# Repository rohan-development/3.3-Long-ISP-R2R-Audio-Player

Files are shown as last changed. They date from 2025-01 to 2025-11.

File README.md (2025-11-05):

The purpose of this ISP, the 8-Bit Audio Player is to play rotary-encoder-selectable-by-name 8-bit, 16 KHz, mono wav files using an R/2R digital to analog converter in place of a traditional I2C or SPI DAC.

The attached code files allow 2 ATmega328Ps to be used in tandem to control a TFT panel, as well as the R2R DAC.

See attached Report.pdf for further details.

Video overview: https://www.youtube.com/watch?v=TbR3IQ8DSpg

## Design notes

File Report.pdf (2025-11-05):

## Project 3.3 Long ISP: 8-Bit R/2R Audio Player

### Purpose

The purpose of this ISP, the 8-Bit Audio Player is to play rotary-encoder-selectable-by-name 8-bit, 16 KHz, mono wav files using an R/2R digital to analog converter (see Project 2.1) in place of a traditional I2C or SPI DAC.

### Reference

Project description: http://darcy.rsgc.on.ca/ACES/TEI4M/2425/ISPs.html#logs
Project proposal: http://darcy.rsgc.on.ca/ACES/TEI4M/2425/images/RJAudio.png Project GitHub: https://github.com/rohan-development/3.3-Long-ISP-R2R-Audio-Player
PCB schematic: https://oshwlab.com/rjamal/ipod-thing

### Theory

There are 2 main classes of audio files: compressed audio, and uncompressed. The dominant audio file format in modern devices is MP3, which is a type of compressed audio. In order to play most standard audio files (regardless of compression), samples of the amplitude at a known sample rate must be obtained. In an uncompressed audio file, the raw sample values are already available in the file; in a compressed audio file, the samples must be obtained by applying an algorithm to the compressed data. These sample rates are then converted to an analog voltage, using a DAC, and amplified to be perceived as sound (see Figure 1).

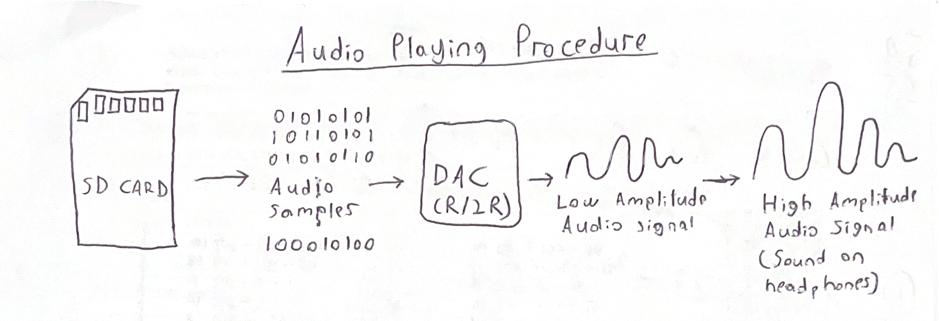
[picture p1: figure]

Figure 1. Audio Playing Sequence Using a DAC

When referencing the Atmega328P, most compression algorithms require significantly more computing power than available to playback in real time. For this reason, the R/2R audio player utilizes Waveform Audio File Format (WAV) files to store audio data, which simply store the raw discrete samples.

The basic concept of 8-Bit R/2R Audio Player comes from Project 2.1, the R/2R DAC. An R/2R ladder, or DAC, is a simple DAC that converts an 8-bit, discrete value, to an analog voltage between 0 and the supply voltage using the principle of voltage division. It included 8 switches that could be turned on or off, for a total of 256 steps between 0 and 5V. By connecting the 8 switch inputs to a microcontroller, a stored 8-bit digital value can be converted to an analog voltage. In this configuration, the R/2R DAC enables the microcontroller to emulate PWM with true analog voltage, instead of a duty cycle-based approximation.

### Procedure

On a very basic level, to play audio, the 8-Bit Audio Player makes use of an R/2R ladder and 8-bit, 16 KHz WAV files (see Theory section). In this configuration, an ATmega328P reads audio samples from an SD card, and sequentially outputs the samples onto the R/2R ladder at a rate of 16 KHz. To advance through the samples reliably at 16 KHz, a timer 1 interrupt is used. The raw signal from the output of the R/2R DAC is filtered through a capacitor, and then amplified through an LM386 audio amplifier, before finally being sent to
headphones through a 3.5 mm audio jack.

The ATmega328P has only 2 KB of memory, while an average WAV file can be in excess of 5000 KB. To get around this limitation, a buffer is used. An 8-bit unsigned array with 256 locations (256 bytes) is created. In this configuration, the first 256 bytes are read from the SD card and placed in the buffer array. Then, a timer1-driven interrupt with a frequency of 16 KHz is initialized Each time the interrupt is triggered, an index is incremented. In the loop() function, the R/2R DAC is constantly updated with the value of the current index of the buffer array. To do this, the PORTD register is directly manipulated. By wiring the LSB of the DAC to pin 0, the second LSB to pin 1, and so on up to the MSB wired to pin 7, a WAV sample value can be directly put on PORTD, which automatically generates the correct analog voltage. When the index reaches the end of the array, it is reloaded. As a result, the buffer needs to be large enough that the MCU does not access the SD card too often to keep up, but also small enough that it can reload the entire buffer reliably between interrupts. Using this process, the original audio signal can be approximated (see Figure 1).

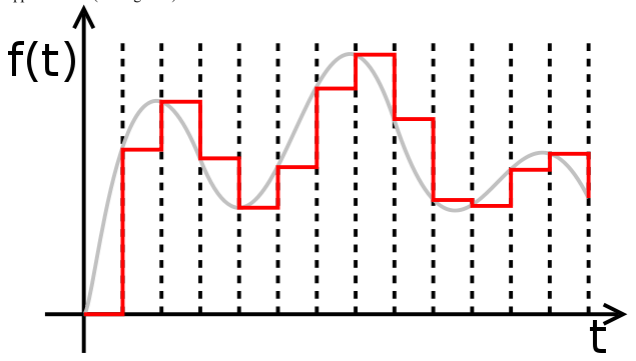
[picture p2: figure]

Figure 1. Audio Signal Approximation using Discrete Signaling

Parts Table
Quantity | Description
13 | Assorted Capacitors
1 | 3.5 mm Audio Jack
25 | ±0.1% 10 KΩ Resistor
38 | Assorted Standard Resistor
2 | Atmega328P SMD MCU
1 | USB-C Connector
1 | LM386 Audio Amplifier
1 | MCP4551T Digipot
2 | 16 MHz Crystal Oscillator

The 8-Bit Audio Player has 2 MCUs used: one “slave” to read from the SD card and update the DAC, and a master to coordinate which song to play, and by responding to user input through a rotary encoder and to control a TFT screen with the song progress and a list of songs. To communicate between MCUs, I2C is utilized. When the master wants to receive any information from the slave, it must send a request. Due to the way that I2C works (see Project 2.6.1), when a request is sent, the same request routine is run. A request routine is a function run when an I2C request is received. This means that the same data point is sent for every request, in a standard configuration. The request routine is simply a function. It is not, strictly speaking, an ISR. This means that many blocks of code can be efficiently run within the request routine, and blocking calls are considered acceptable.

To request multiple data points, a command code
system is implemented. In this configuration, the master sends a code corresponding to a data point, which is placed into a buffer. Then, the master sends a request. Within the request routine, a
subroutine is included for each point (see Figure 2).

The master MCU only has direct access to the display, the rotary encoder, and the I2C bus. Since it does not have access to the SD card, it cannot directly read the song names to put on the display. To read the song names, it requests the data from the player MCU. To do this, it first sends a value of 2, to place in the code buffer (see Figure 2). Then, it requests 32 bytes from the player, which reads the SD card, parses it into a character array buffer, and sends 1 character (byte) at a time to the master which reconstructs the data and parses it into a 2D array of characters. Since the master can only hold a finite number of song names in its 2 KB of memory, the player maintains a global index based on the last song sent. This means that on the next song name request, the next song is automatically sent.

In addition to a request routine, the player MCU has
a receive routine. Unlike the request routine, the
receive routine is an ISR, and it is called when data is written to the player. To aid the command code system, the first byte received is always the code.
Some codes warrant a second byte (see Figure 3).

The code system is global, and not specific to the data direction. As a result, most codes are only valid in either Figure 2 (MISO), or Figure 3 (MOSI). The exception to this is the code 0, which, strictly speaking, corresponds to a song change. When a 0 is received, the songChanged flag is set, and a second byte is read, which is stored into the song number buffer. On the next iteration of the loop, the songChanged flag is picked up, and the song is set to the number in the song number buffer. When the song is changed, the master requires the length of the song each time, which is stored on the slave. As a result, the master sends a data request. Since the code 0 corresponds to a song change, an additional request code is not required; the data point requested immediately after a song change is always song length.

Figure 2. Code Data Correspondences
Code | Data Point
0 | Song length
1 | N/A
2 | Song names
3 | Number of songs

Figure 3. Code Action Correspondences
Code | Action | Extra bytes
0 | Changes song | 1
1 | Toggles Playback | 0
2 | N/A | 0
3 | N/A | 0

To select the desired song, a simple for loop is utilized. In the loop, an index is set such that the loop runs song times. In the loop are two important parts: a next file line, and a hidden file skipping line. In this configuration, since the loop is run a certain number of times, the next file is chosen the same number of times, skipping to the desired file. The index number is built in the same fashion which maps an index value to the filename, so a number can be easily linked with a filename from the display. The hidden file skipping line simply decrements the loop index if the file starts with “._”.

When a song is selected, after the master updates
the slave, it goes to the “now playing” screen
(see Figure 4). This screen shows a music icon, which is stored as an array in program memory, to save RAM. It also shows the current song progress in seconds, the total song length, a progress bar, and the name of the track (see Figure 4).

To display this screen, when the song is selected, the music icon is drawn from program memory (only once, which saves resources). The song track name is also drawn once. Then, a timer1-driven interrupt which triggers once per second is started, updating the song progress in real time. To display the progress bar, the map function is used. It simply maps the song progress from a value between 0 and songLength, to a value between 0 and 100. The progress bar is 100 pixels wide, so a green rectangle with the result of the map is drawn
overtop of the white background bar.

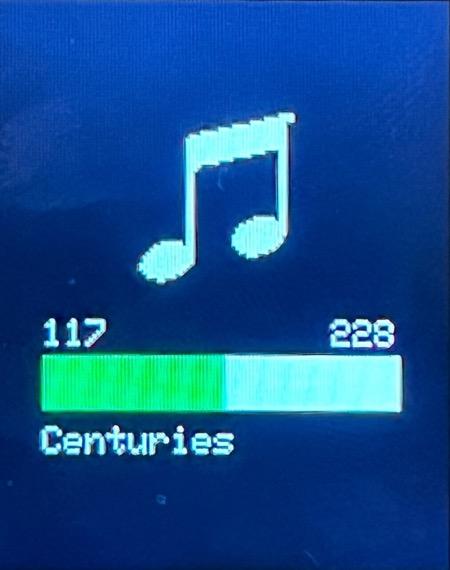
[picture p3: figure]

On the now playing screen, when the rotary encoder is pressed, the master sends a code of 1 to the player, which toggles the OCIE1A bit of the TIMSK register. This bit enables or disables the execution of the ISR on the overflow of timer1. This effectively toggles playback. Since the MCU playing the music is independent from the one connected to the screen, the progress bar is updated independently as well; when playback is started, the master downloads the song length and starts a timer. It does not send a request with the song progress each second.

The PCB for the 8-Bit Audio Player includes a boost converter, as well as a battery charging IC. This allows the 5 V system to be used effectively with a 3.7 V lithium-ion battery, with charging over USB-C. The boost converter steps the voltage up from 3.7 V to 5 V. The battery charging IC regulates the 5 V from the USB-C connector to effectively charge the lithium battery.

Figure 4. Now Playing Screen

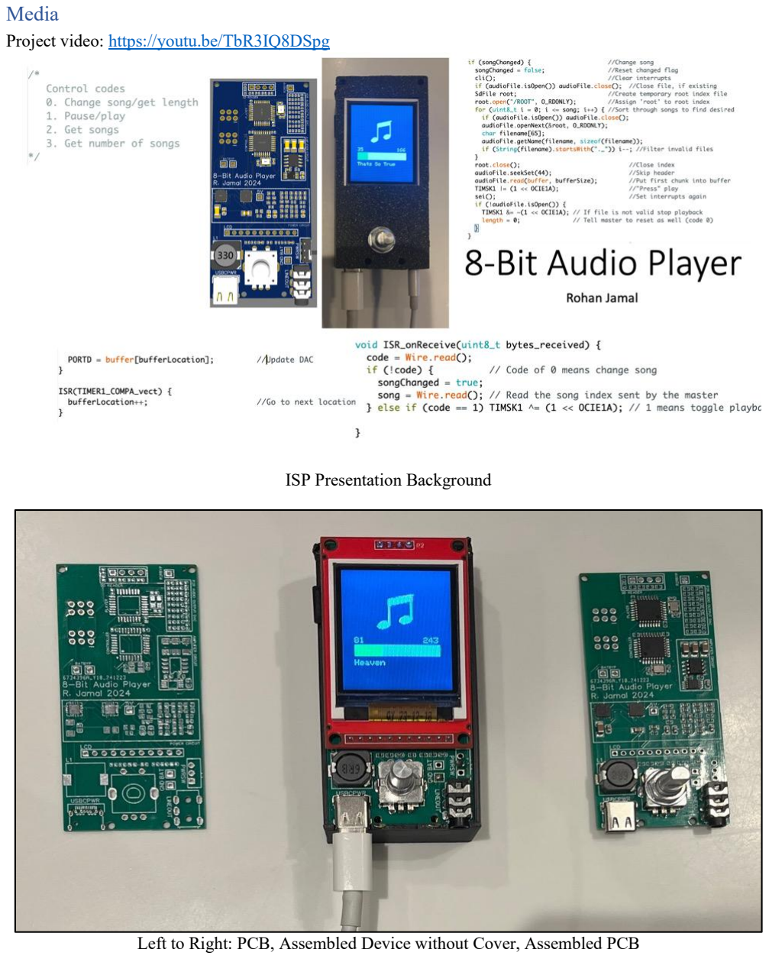
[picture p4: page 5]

### Media

Project video: https://youtu.be/TbR3IQ8DSpg

ISP Presentation Background

Left to Right: PCB, Assembled Device without Cover, Assembled PCB

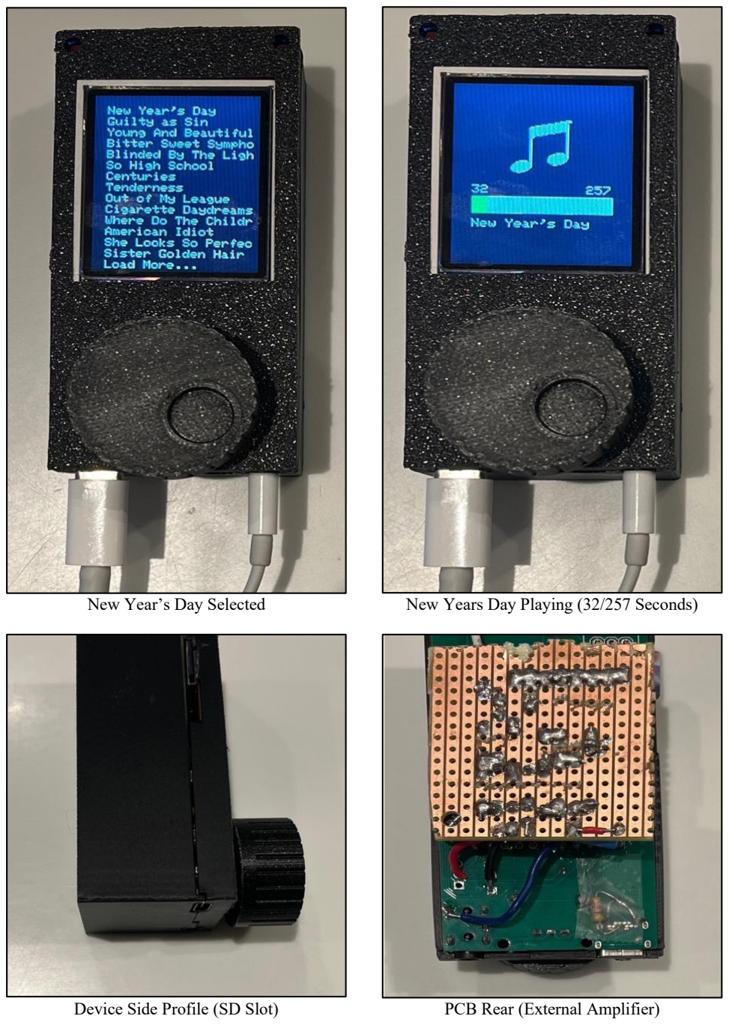
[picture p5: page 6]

New Year’s Day Selected | New Years Day Playing (32/257 Seconds)
Device Side Profile (SD Slot) | PCB Rear (External Amplifier)

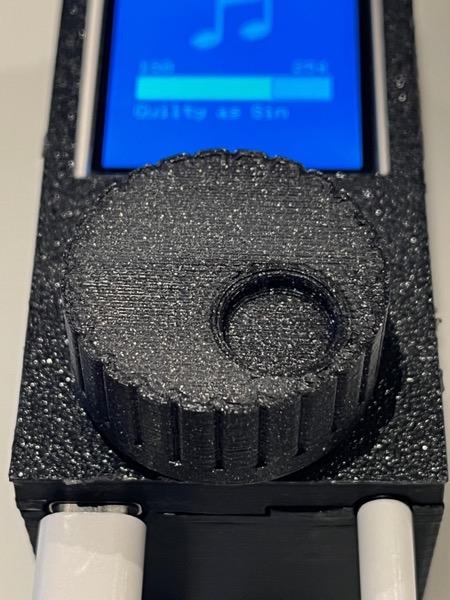
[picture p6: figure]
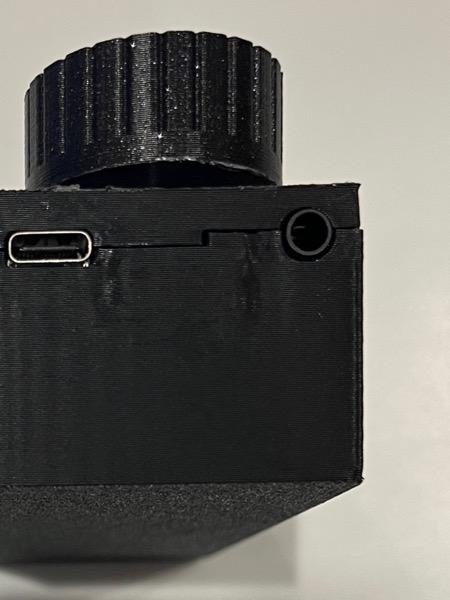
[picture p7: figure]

Rotary Encoder Handle | Device Ports (Bottom)

### Reflection

This has definitely been my favourite ISP thus far. Out of all my ISPs, I think this is my most functional one. My bike speedometer worked in the end, but it was never practical. This audio player is completely practical for sitting in one place whilst doing homework and listening to music. I learned a ton about how music is played in general, I learned a ton of strategies in code (it’s just practice, I suppose), and I really feel that I pushed my PCB design during this project. Overall, I am super happy with the result as I feel that I accomplished just about everything that I said I would (more in some areas). The only “copout” that I ended up going with was 8 bits instead of 12, as all information I found pointed towards inaccuracies of the R/2R ladder beyond 8-10 bits. It also would not have made much sense from a port perspective.

I think that this is really not a testament to any skill but time management. This is something I normally struggle with, but I had my PCB done early enough that I was not scrambling at the last minute, and I had much time to debug and perfect my code and 3D design.

I know that I could have used an ESP32, or some other microcontroller to easily play the audio without an external DAC, but for me, the real satisfaction was building my own DAC from scratch, and working with the limited resources of the 328P

That being said, there are some things that I hope to fix: I think that if I get a chance, I will reorder the PCB, without the power circuit and use larger resistors and capacitors so I can surface mount them myself in order to address a few issues (such as lack of volume control and the absence of a functional onboard amplifier). Overall, this was a great project, and while thinking about my next ISP, I definitely have audio in mind. (My code and EasyEDA files are included in the GitHub and Oshwlab links in Reference).

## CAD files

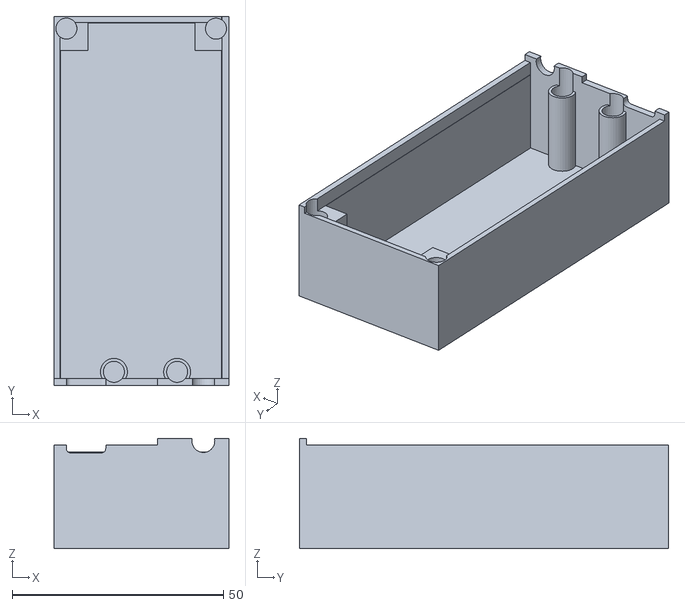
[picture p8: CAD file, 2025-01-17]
Case bottom.stl
41.4 x 87.4 x 26.1

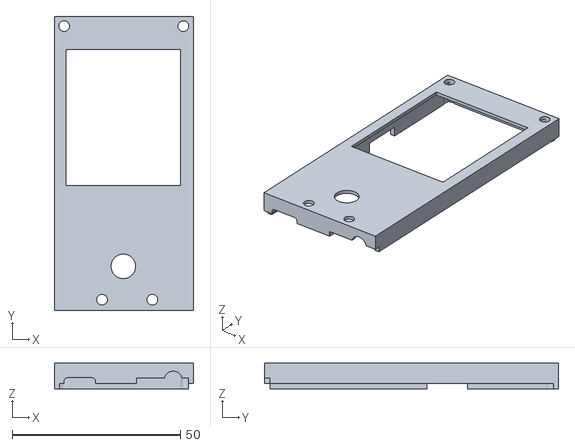
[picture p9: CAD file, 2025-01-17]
Case top.stl
41.4 x 87.4 x 7.69

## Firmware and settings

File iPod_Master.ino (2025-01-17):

const unsigned char note [] PROGMEM = {
  0x00, 0x00, 0x00, 0x00, 0x00, 0x00, 0x00, 0x00, 0x00, 0x00, 0x00, 0x00, 0x00, 0x00, 0x00, 0x00,
  0x00, 0x00, 0x00, 0x78, 0x00, 0x00, 0x00, 0x00, 0x00, 0x07, 0xf8, 0x00, 0x00, 0x00, 0x00, 0x00,
  0x7f, 0xe0, 0x00, 0x00, 0x00, 0x00, 0x0f, 0xff, 0xe0, 0x00, 0x00, 0x00, 0x00, 0xff, 0xff, 0xe0,
  0x00, 0x00, 0x00, 0x1f, 0xff, 0xff, 0xe0, 0x00, 0x00, 0x00, 0xff, 0xff, 0xff, 0xe0, 0x00, 0x00,
  0x01, 0xff, 0xff, 0xff, 0xe0, 0x00, 0x00, 0x01, 0xff, 0xff, 0xff, 0xe0, 0x00, 0x00, 0x01, 0xff,
  0xff, 0xff, 0xe0, 0x00, 0x00, 0x01, 0xff, 0xff, 0xf8, 0x60, 0x00, 0x00, 0x01, 0xff, 0xff, 0x80,
  0x60, 0x00, 0x00, 0x01, 0xff, 0xf0, 0x00, 0x60, 0x00, 0x00, 0x01, 0xff, 0x00, 0x00, 0x60, 0x00,
  0x00, 0x01, 0xe0, 0x00, 0x00, 0x60, 0x00, 0x00, 0x01, 0xc0, 0x00, 0x00, 0x60, 0x00, 0x00, 0x01,
  0x80, 0x00, 0x00, 0x60, 0x00, 0x00, 0x01, 0x80, 0x00, 0x00, 0x60, 0x00, 0x00, 0x01, 0x80, 0x00,
  0x00, 0x60, 0x00, 0x00, 0x01, 0x80, 0x00, 0x00, 0x60, 0x00, 0x00, 0x01, 0x80, 0x00, 0x00, 0x60,
  0x00, 0x00, 0x01, 0x80, 0x00, 0x00, 0x60, 0x00, 0x00, 0x01, 0x80, 0x00, 0x00, 0x60, 0x00, 0x00,
  0x01, 0x80, 0x00, 0x00, 0x60, 0x00, 0x00, 0x01, 0x80, 0x00, 0x00, 0x60, 0x00, 0x00, 0x01, 0x80,
  0x00, 0x00, 0x60, 0x00, 0x00, 0x01, 0x80, 0x00, 0x00, 0x60, 0x00, 0x00, 0x01, 0x80, 0x00, 0x00,
  0x60, 0x00, 0x00, 0x01, 0x80, 0x00, 0x00, 0x60, 0x00, 0x00, 0x01, 0x80, 0x00, 0x3f, 0x60, 0x00,
  0x00, 0x01, 0x80, 0x00, 0xff, 0xe0, 0x00, 0x00, 0x01, 0x80, 0x03, 0xff, 0xe0, 0x00, 0x00, 0x01,
  0x80, 0x07, 0xff, 0xe0, 0x00, 0x00, 0x01, 0x80, 0x07, 0xff, 0xe0, 0x00, 0x00, 0x01, 0x80, 0x0f,
  0xff, 0xc0, 0x00, 0x00, 0x01, 0x80, 0x0f, 0xff, 0xc0, 0x00, 0x00, 0xfd, 0x80, 0x0f, 0xff, 0x80,
  0x00, 0x03, 0xff, 0x80, 0x07, 0xff, 0x00, 0x00, 0x07, 0xff, 0x80, 0x03, 0xfc, 0x00, 0x00, 0x0f,
  0xff, 0x80, 0x00, 0xe0, 0x00, 0x00, 0x1f, 0xff, 0x80, 0x00, 0x00, 0x00, 0x00, 0x1f, 0xff, 0x80,
  0x00, 0x00, 0x00, 0x00, 0x3f, 0xff, 0x00, 0x00, 0x00, 0x00, 0x00, 0x3f, 0xfe, 0x00, 0x00, 0x00,
  0x00, 0x00, 0x1f, 0xfc, 0x00, 0x00, 0x00, 0x00, 0x00, 0x0f, 0xf0, 0x00, 0x00, 0x00, 0x00, 0x00,
  0x01, 0x80, 0x00, 0x00, 0x00, 0x00, 0x00, 0x00, 0x00, 0x00, 0x00, 0x00, 0x00, 0x00
};                                            //Music note graphic in program memory

#include <Wire.h>                             //I2C library for communication with player MCU
#include <Adafruit_GFX.h>                     //Core graphics library
#include <Adafruit_ST7735.h>                  //ST7735 (TFT) library
#include <SPI.h>                              //SPI Library for TFT display
#define PLAYER 0x55                           //I2C address of player (slave)
#define PIN_A 2                               //Pin "A" of rotary encoder
#define PIN_B 1                               //Pin "B" of rotary encoder
#define TFT_CS    6                           //Chip select of TFT
#define TFT_RST   5                           //Reset pin of TFT
#define TFT_DC    4                           //Data/Command pin of TFT
char songNames[25][33] {};                    //Buffer to hold song names
Adafruit_ST7735 tft = Adafruit_ST7735(TFT_CS, TFT_DC, TFT_RST); //TFT object
volatile bool progBar = false;                //Flag to update display progress bar
bool displaying = false;                      //Flag to keep track of displaying status
bool reload = false;                          //Flag for when to reload song index
volatile bool sw = false;                     //Rotary encoder pressed flag
volatile bool pre0 = false;                   //Previous state of rotary encoder switch
bool subtracted = false;                      //Keeps track of whether the index was subtracted
int8_t count = 0;                             //Variable to keep track of current display index
uint16_t numSongs;                            //Number of songs available
volatile bool pinA, pinB;                     //Bools to store states of A and B
uint8_t preA;                                 //Previous pin A state
volatile bool triggered = false;              //Flag for a change in rotary encoder position
volatile uint8_t selectedSong = 0;            //Buffer to store selected song
uint8_t songLocation = 0;                     //Song index
uint16_t songLength = 0;                      //Length of song
volatile uint16_t songProgress = 0;           //Progress through a song

void setup() {
  Wire.begin();                               //Initialize I2C bus in master mode
  tft.initR(INITR_BLACKTAB);                  //Initialize TFT panel
  tft.fillScreen(ST77XX_BLACK);               //Fill screen with black
  tft.setTextColor(ST77XX_WHITE);             //Set colour to white
  tft.setTextSize(1);                         //Set text size to 1
  Wire.beginTransmission(PLAYER);             //Start a transmission to the player MCU
  Wire.write(3);                              //Puts a 3 into the code buffer of slave (# of songs)
  Wire.endTransmission();                     //Ends transmission and writes the byte
  Wire.requestFrom(PLAYER, 2);                //Request 2 bytes from slave (# of songs = 2 bytes)
  while (!Wire.available());                  //Wait for bytes to become available
  numSongs = Wire.read() << 8;                //Receive high byte
  numSongs |= Wire.read();                    //Receive low byte
  if (numSongs < 25) getSongs(numSongs);      //When there are les than 25 songs receive all names
  else {                                      //When there are 25 or more than 25, get 24
    getSongs(24);                             //Get 24 song names
    numSongs = 25;                            //Add a 25th row
    strcpy(songNames[24], "Load More...");    //In the 25th row, but a "Load More..." button
  }
  cli();                                      //Clear global interrupts
  TCCR1A = 0;                                 //Normal mode, no PWM
  TCCR1B = 0;                                 //Stop the timer (will start it later)
  TCNT1 = 0;                                  //Clear the timer count
  OCR1A = 62500 - 1;                          //62500 ticks of timer1 = 1/256 second
  TCCR1B |= (1 << WGM12);                     //CTC mode
  TCCR1B |= (1 << CS12);                      //Prescaler 256
  PCICR |= (1 << PCIE2);                      //Enable PCINT for PORTD
  PCMSK2 |= (1 << PCINT16) | (1 << PCINT17);  //Mask for 0 and 1 (pins 0 and 1)
  sei();                                      //Set the global interrupt flag
  attachInterrupt(digitalPinToInterrupt(2), ISR_rotary, CHANGE);  //Interrupt for encoder
  updateScreen();                             //Update the tft screen
  pinA = digitalRead(PIN_A);                  //Get the state of pin A of encoder
  pinB = digitalRead(PIN_B);                  //Get the state of pin B of encoder
  preA = pinA;                                //Put a value into preA
}

void loop() {
  rotaryUpdate();                             //Update the count (if triggered is true)
  if (sw) {                                   //When rotarty encoder select is pressed...
    sw = false;                               //Reset flag
    if (displaying) {                         //If on the "playing" screen, select toggles playback
      Wire.beginTransmission(PLAYER);         //Start a transmission to the slave MCU
      Wire.write(1);                          //Code of 1 means toggle playback
      Wire.endTransmission();                 //End the transmission/send bytes
      TIMSK1 ^= (1 << OCIE1A);                //Toggle the status of the progress bar
    }
    else if (count != 24) {                   //When not on the load more songs line, load selected
      songProgress = 0;                       //Reset progress bar
      cli();                                  //Clear interrupts
      TIMSK1 |= (1 << OCIE1A);                //Start progress bar
      sei();                                  //Start global interrupts again
      Wire.beginTransmission(PLAYER);         //Begin I2C transmission to player MCU
      Wire.write(0);                          //Code of 0 means change song
      Wire.write(count + (24 * (songLocation / 25))); //Send desired song (including the page)
      Wire.endTransmission();                 //End the transmission/send bytes
      Wire.requestFrom(PLAYER, 2);            //Request 2 bytes from the player MCU
      while (!Wire.available());              //Wait for bytes to become available
      songLength = (Wire.read() << 8);        //Receive high byte of length
      songLength |= Wire.read();              //Receive low byte of length
      tft.fillScreen(ST77XX_BLACK);           //Clear the screen
      tft.drawBitmap(39, 30, note, 50, 50, ST77XX_WHITE);   //Draw the music note graphic
      tft.setCursor(14, 120);                 //Go to 14, 120 on the screen
      tft.print(songNames[count]);            //Print the name of the current song playing
      displaying = true;                      //Enable the "displaying" flag
    }
    else reload = true;                       //If it was on the load more button, set the flag
  }
  if (progBar && displaying) {                //When on music note and update flag is set...
    progBar = false;                          //Reset progBar flag
    tft.fillRect(10, 90, 100, 8, ST77XX_BLACK); //Clear the number of elapsed seconds area
    tft.setCursor(14, 90);                    //Go to elapsed seconds area
    tft.print(songProgress);                  //Print elapsed seconds
    tft.setCursor(95, 90);                    //Go to total seconds area
    tft.print(songLength);                    //Print total seconds
    uint8_t mapBuf = map(songProgress, 0, songLength, 0, 100);      //Buffer for mapped progress
    tft.fillRect(14 + mapBuf, 100, 100 - mapBuf, 15, ST77XX_WHITE); //Draw progBar background
    tft.fillRect(14, 100, mapBuf, 15, ST77XX_GREEN);                //Draw progress bar
  }
  if (reload) {                               //If load more button was pressed
    reload = false;                           //Reset flag
    count = 0;                                //Set selector position to 0
    Wire.beginTransmission(PLAYER);           //Start a transmission to the player MCU
    Wire.write(3);                            //Write a code of 3 (# of songs)
    Wire.endTransmission();                   //End transmission/send bytes
    Wire.requestFrom(PLAYER, 2);              //Request 2 bytes from the player
    while (!Wire.available());                //Wait for bytes to become available
    numSongs = Wire.read() << 8;              //Receive high byte
    numSongs |= Wire.read();                  //Receive low byte
    if (numSongs < 25) getSongs(numSongs);    //If number of songs is less than 25, receive all names
    else {                                    //If number of songs is 25 or more...
      getSongs(24);                           //Get 24 songs
      numSongs = 25;                          //Add a 25th row
      strcpy(songNames[24], "Load More...");  //Put a "Load More..." button on row 25
    }
    updateScreen();                           //Update the screen with new songs
  }
}
void getSongs(uint8_t maxSong) {              //Function to get "maxSong" number of song names
  memset(songNames, '\0', sizeof(songNames));   //Clear array
  Wire.beginTransmission(PLAYER);             //Start a transmission to the player MCU
  Wire.write(2);                              //2 means send songs
  Wire.endTransmission();                     //End transmission/send bytes
  uint8_t row;                                //Row index
  for (row = 0; row < maxSong; row++) {       //Loop maxSong number of times
    Wire.requestFrom(PLAYER, 32);             //Request 32 bytes (characters)
    for (uint8_t charac = 0; Wire.available(); charac++)  //Receive however many bytes available
      songNames[row][charac] = Wire.read();   //Receive 1 byte (character) at a time
    songNames[row][19] = '\0';                //Put null terminator into location 19 (display length)
    if (songNames[row][0] == 3) break;        //If received "end of text character", stop the loop
  }
  if (songNames[row][0] != 3)                 //For all valid song names...
    songLocation += maxSong;                  //Update song index
  else songLocation = 0;                      //If invalid, reset the song index to loop back
}
void ISR_rotary() {                           //Rotary encoder update "change" ISR
  triggered = true;                           //Activate 'changed' flag
  pinA = digitalRead(PIN_A);                  //Store state of pin 'A'
  pinB = digitalRead(PIN_B);                  //Store state of pin 'B'

}
ISR(TIMER1_COMPA_vect) {                      //Progress bar update ISR
  progBar = true;                             //Set progress bar update flag
  if (songProgress < songLength)              //If song is playing...
    songProgress++;                           //Add a second to the progress
}
ISR(PCINT2_vect) {                            //Pin change interrupt for PORTD
  if (PIND & (1 << PD0)) {                    //If the encoder switch was high...
    sw = true;                                //Set switch pressed flag
    pre0 = true;                              //Set status flag to detect falling edge
  }
  else if (pre0) pre0 = false;                //Reset status flag on falling edge
  else {                                      //If change was detected on encoder...
    triggered = true;                         //Set encoder changed flag
    pinA = digitalRead(PIN_A);                //Store state of pin A
    pinB = digitalRead(PIN_B);                //Store state of pin B
  }
}
void updateScreen() {                         //Function to update the screen
  tft.fillScreen(ST77XX_BLACK);               //Clear LCD when the displayed string changes
  for (uint8_t i = 0; i < numSongs; i++) {    //Display all valid songs
    tft.setCursor(10, 10 * (i + 1));          //Set cursor to next line
    if ((count + i) < numSongs)               //If the song is valid...
      tft.print(songNames[count + i]);        //Print the song
  }
}
void rotaryUpdate() {                         //Function to detect rotary encoder direction
  if (triggered) {                            //When change flag has tripped...
    triggered = false;                        //Reset change flag
    displaying = false;                       //Exit now playing screen
    if (pinA != preA)                         //Determine direction (intermediary step)
      preA = pinA;                            //Store previous state
    else {  
      if ((pinA == pinB)) {                   //Determine direction
        if (!subtracted) count++;             //Increment time (direction A)
        else subtracted = false;              //Clear subtracted flag if added
      }
      else {                                  //Other direction
        count--;                              //Decrement time (direction B)
        subtracted = true;                    //Set subtracted flag
      }
      if (count < 0) count = 0;               //Bottom bookend
      if (count >= numSongs) count = numSongs - 1;  //Top bookend
      updateScreen();                         //Update the screen
    }
  }
}

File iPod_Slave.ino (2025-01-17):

#include <Wire.h>                     //I2C communication with master
#include <SPI.h>                      //SPI for SDFAT
#include <SdFat.h>                    //SDFAT to read from SD card
#define USE_LONG_FILE_NAMES 1         //Enable Long File Names for SDFAT
#define I2C_ADDR 0x55
/*
   Control codes
   0. Change song/get length
   1. Pause/play
   2. Get songs
   3. Get number of songs
*/
#define chipSelect 8                  //SD chip select pin
#define bufferSize 256                //Size of audio sample buffer, in bytes
SdFat SD;                             //SD object
SdFile audioFile;                     //SD File object for WAV file
uint8_t buffer[bufferSize];           //Buffer to play hold audio samples
volatile uint8_t code;                //Buffer to hold I2C control code
volatile uint8_t song = 0;            //Buffer to hold playing song number
volatile uint16_t bufferLocation = 0; //Variable to store index of audio buffer
uint16_t numSongs;                    //Number of available songs to send to master
volatile bool songChanged = false;    //Flag to keep track of song changes
volatile uint8_t songLocation = 1;    //Index for which song is selected
volatile uint32_t length;             //Buffer to hold length of the song

void setup() {
  Wire.begin(I2C_ADDR);               //Initialize I2C communication
  Wire.onReceive(ISR_onReceive);      //I2C receive ISR definition
  Wire.onRequest(ISR_onRequest);      //I2C request ISR definition
  SD.begin(chipSelect, SPI_FULL_SPEED);  //Initialize SD card with full speed
  SdFile root;                        //Creates SD file object
  root.open("/ROOT", O_RDONLY);       //Initiallizes SD file object with /root directory
  SdFile entry;                       //Creates SD file object
  entry.openNext(&root, O_RDONLY);    //Initiallizes SD file object with "root" file
  char filename[65];                  //Buffer for filename
  for (numSongs = 0; entry.isFile(); numSongs++) {  //Loops to a desired file number
    if (entry.isOpen()) entry.close();//Closes existing file to free memory
    entry.openNext(&root, O_RDONLY);  //Opens next file
    entry.getName(filename, sizeof(filename));  //Puts name of current file into buffer
    if (String(filename).startsWith("._")) numSongs--;  //Discounts hidden files
  }
  DDRD = 0xFF;                        //Set DAC pins as output
  cli();                              //Clear global interrupts
  TCCR1A = 0;                         //Normal mode, no PWM
  TCCR1B = 0;                         //Stop the timer (will start it later)
  TCNT1 = 0;                          //Clear the timer count
  OCR1A = 1000 - 1;                   //1000 ticks of timer1 = 62.5 ms
  TCCR1B |= (1 << WGM12);             //CTC mode
  TCCR1B |= (1 << CS10);              //Prescaler 1 (no prescaler)
  sei();                              //Set the global interrupt flag
}
void loop() {
  if (songChanged) {                      //Changes song when flag true
    songChanged = false;                  //Reset changed flag
    cli();                                //Clear interrupts
    if (audioFile.isOpen()) audioFile.close();  //Close file, if existing
    SdFile root;                          //Create temporary root index file
    root.open("/ROOT", O_RDONLY);         //Assign 'root' to root index
    for (uint8_t i = 0; i <= song; i++) { //Sort through songs to find desired song
      if (audioFile.isOpen()) audioFile.close();  //Closes existing file to free memory
      audioFile.openNext(&root, O_RDONLY);//Opens next file
      char filename[65];                  //Buffer for filename
      audioFile.getName(filename, sizeof(filename));  //Puts name of file into buffer
      if (String(filename).startsWith("._")) i--; //Filter invalid files
    }
    root.close();                               //Close index
    audioFile.seekSet(44);                      //Skip header
    audioFile.read(buffer, bufferSize);         //Put first chunk into buffer
    TIMSK1 |= (1 << OCIE1A);                    //"Press" play
    sei();                                      //Set interrupts again
    if (!audioFile.isOpen()) {                  //If file is invalid, don't play
      TIMSK1 &= ~(1 << OCIE1A);                 //If file is not valid stop playback
      length = 0;                               //Tell master to reset as well (0=invalid)
    }
  }
  if (bufferLocation == bufferSize - 1) {       //Reload audio buffer
    bufferLocation = 0;                         //Initiallize buffer index
    audioFile.read(buffer, bufferSize);         //Place chunk into buffer
  }
  if (!audioFile.available())                   //Check for end of song (handle by master)
    TIMSK1 &= ~(1 << OCIE1A);                   //Stop playback
  PORTD = buffer[bufferLocation];               //Update DAC
}

ISR(TIMER1_COMPA_vect) {
  bufferLocation++;                             //Go to next location in audio buffer
}
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
